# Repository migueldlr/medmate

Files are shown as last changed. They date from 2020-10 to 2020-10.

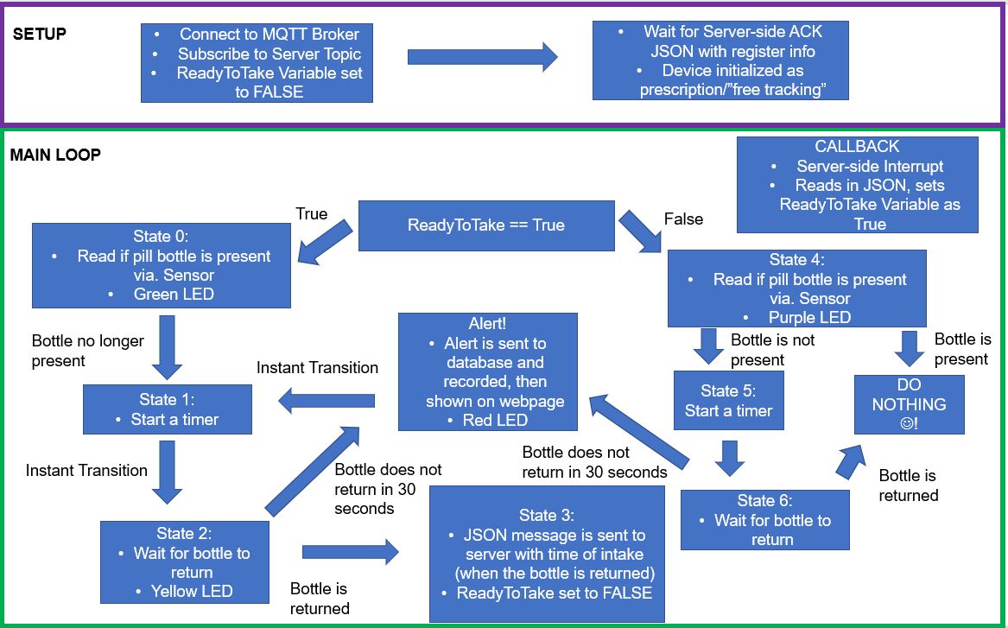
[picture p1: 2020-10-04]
images/MedMate State Machine.JPG

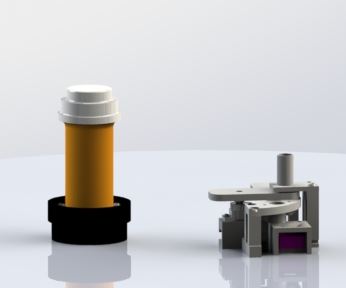
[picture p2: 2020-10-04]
images/MedMate Render.JPG

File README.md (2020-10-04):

# MedMate

`device/` contains the device's Arduino code

`server/` contains the Python that times events and facilitates communication between the device and the database

`client/` contains the React/TypeScript web project that allows users to input their prescriptions, track their medications, and receive updates

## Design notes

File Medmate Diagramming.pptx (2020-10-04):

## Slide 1

SETUP

- Connect to MQTT Broker
- Subscribe to Server Topic
- ReadyToTake Variable set to FALSE

- Wait for Server-side ACK JSON with register info
- Device initialized as prescription/”free tracking”

MAIN LOOP

CALLBACK
- Server-side Interrupt
- Reads in JSON, sets ReadyToTake Variable as True

State 4:
- Read if pill bottle is present via. Sensor
- Purple LED

True

ReadyToTake == True

False

State 0:
- Read if pill bottle is present via. Sensor
- Green LED

Bottle no longer present

Alert!
- Alert is sent to database and recorded, then shown on webpage
- Red LED

Instant Transition

Bottle is not present

State 5:
Start a timer

Bottle is present

State 1:
- Start a timer

Instant Transition

State 2:
- Wait for bottle to return
- Yellow LED

Bottle does not return in 30 seconds

State 3:
- JSON message is sent to server with time of intake (when the bottle is returned)
- ReadyToTake set to FALSE

DO NOTHING !

Bottle is returned

Bottle does not return in 30 seconds

State 6:
- Wait for bottle to return

Bottle is returned

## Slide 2

Prescription

User enters the following information
- Time of Prescription Intake (9am, 4pm)
- Frequency (Daily, Biweekly)
- Prescription Amount (# of pills)
- Prescription Name (Tylenol)
Server keeps track of when user should take medicine
- When it is time →
  - Sends JSON callback
  - Controller starts recording for medicine intake
  - Server stores time of intake into database

Free Tracking

User enters the following information:
- Prescription Name (Tylenol)
Server only tracks when user takes medicine
  - Controller can start recording for medicine intake at any point
  - Server stores time of intake into database

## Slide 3

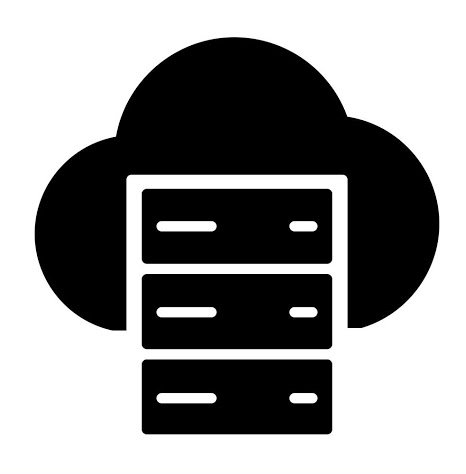
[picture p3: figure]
Best Free Icon Server Cartoon Vector Drawing » Free Vector Art, Images, Graphics & Clipart

Server keeps track of when user should take medicine

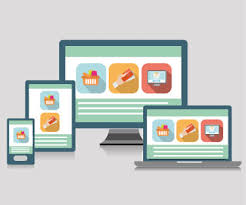
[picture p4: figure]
Web Page Cartoon - 2yamaha.com

User enters their prescription information

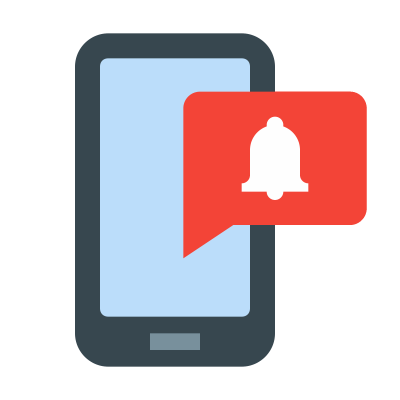
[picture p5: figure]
Notifications with Vera – Vera

User is notified to take medicine

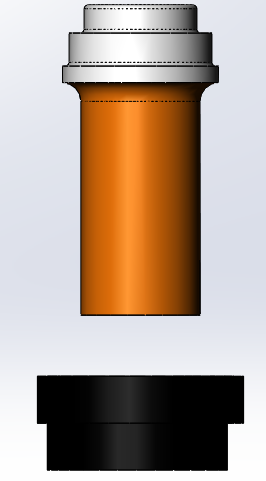
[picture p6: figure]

Pill bottle is taken off MedMate

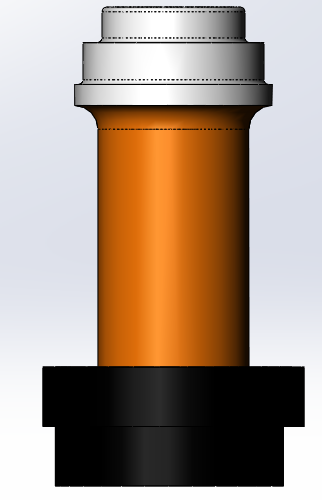
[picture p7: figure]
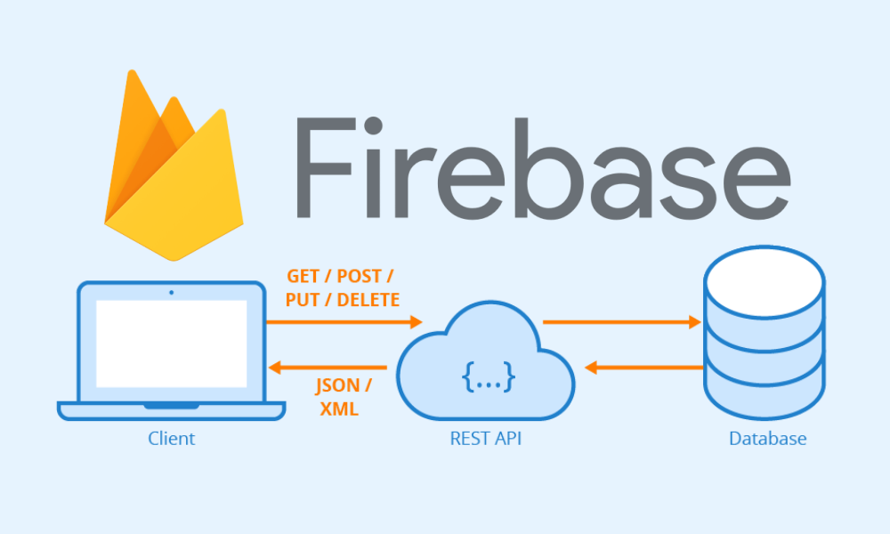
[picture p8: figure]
Firebase Cloud Functions Tutorial - Creating a REST API
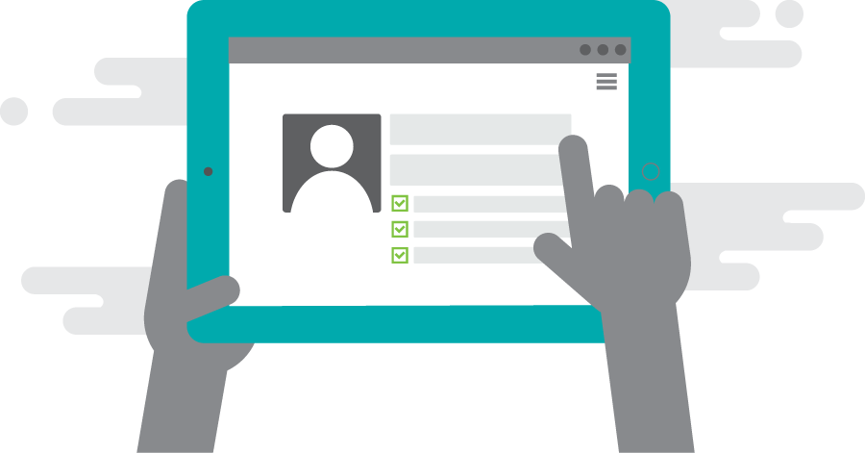
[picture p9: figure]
Streamlining Patient History Collection | Vynamic

Pills are consumed and bottle is put back on MedMate

Time of Intake is uploaded to Database

Patient History shown on Webpage

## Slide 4

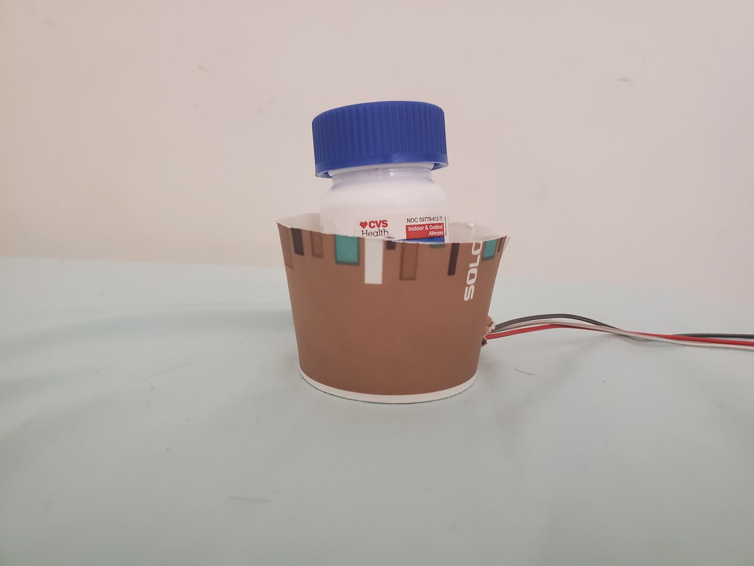
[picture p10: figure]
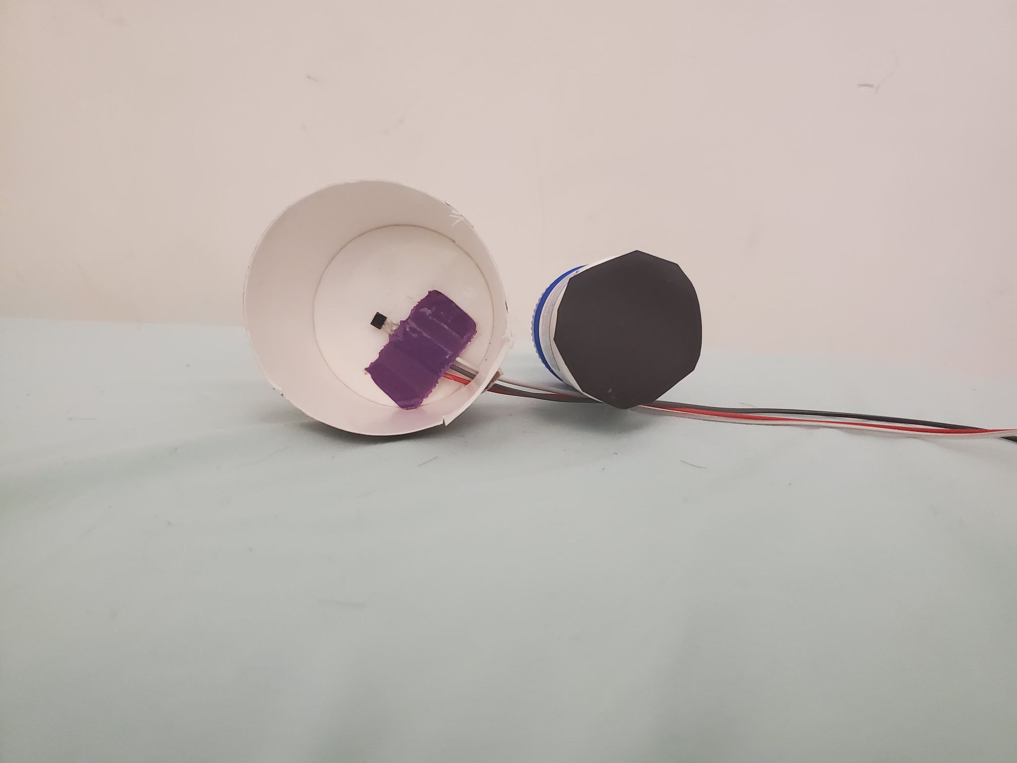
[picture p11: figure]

Pill Bottle

Paper Cup

DRV5053 Hall Sensor

Magnet

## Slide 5

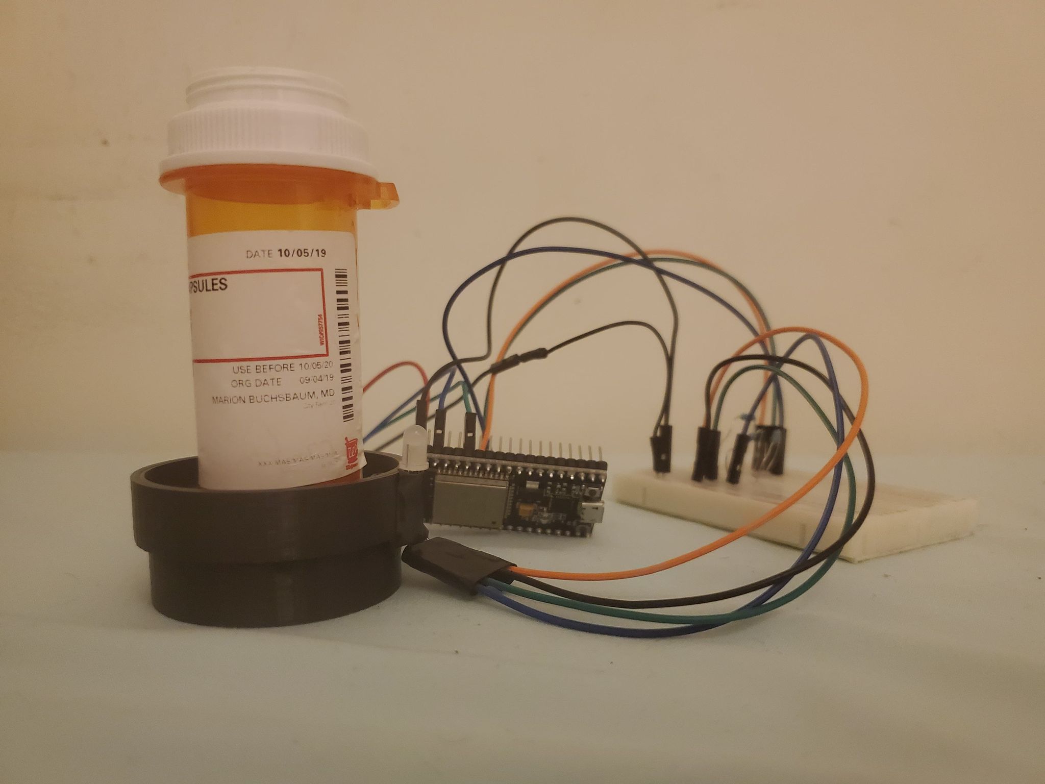
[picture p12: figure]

Pill Bottle

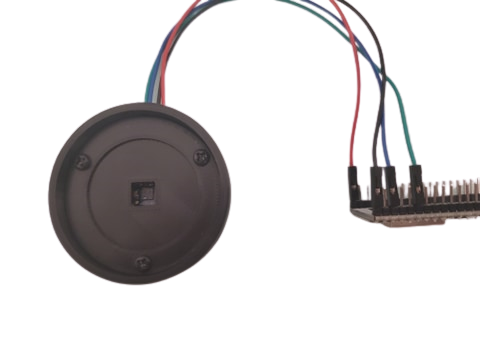
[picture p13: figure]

ESP32

VCNL4010 Proximity Sensor

MedMate

Multicolor LED

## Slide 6

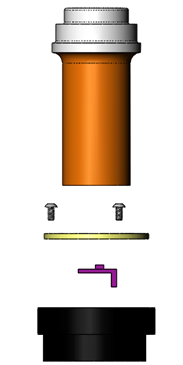
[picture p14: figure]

Pill Bottle

M3 Screws

VCNL4010 Proximity Sensor

Top Lid

Multicolor LED

Main Housing

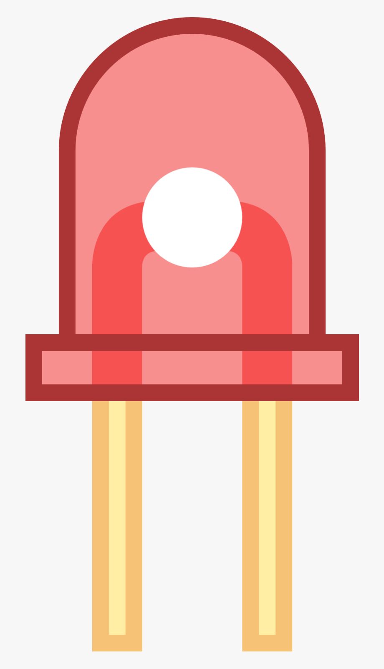
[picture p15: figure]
Image Result For Led Icon - Led Diode Icon Png , Transparent Cartoon, Free Cliparts & Silhouettes - NetClipart

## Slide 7

ESP32

VCNL4010

SCL (P22)

SDA (P21)

Red (P32)

Green (P33)

Blue (P25)

GND

SDA

SCL

3.3V

GND

Multicolor LED

Green

3.3V

220Ω

GND

Red

220Ω

220Ω

Blue

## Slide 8

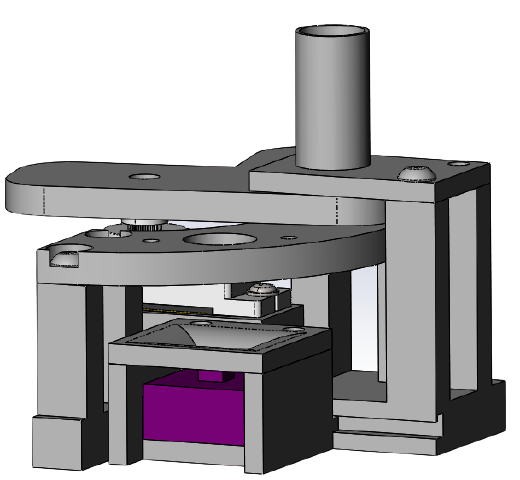
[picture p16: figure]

Rotating Cam

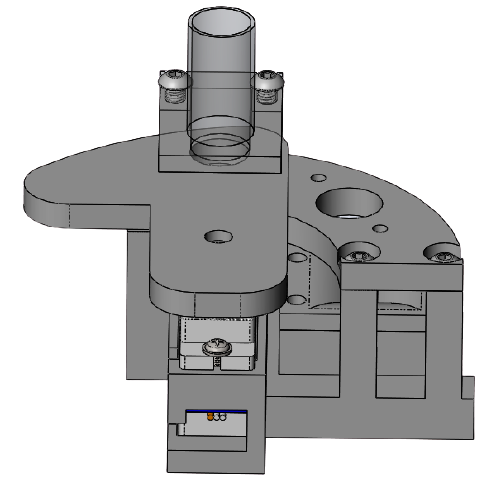
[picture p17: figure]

Pill Tube

Sorting Piece

Pill

VCNL4010 Proximity Sensor

Pill

Pill Holder

SG90 Servo

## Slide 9

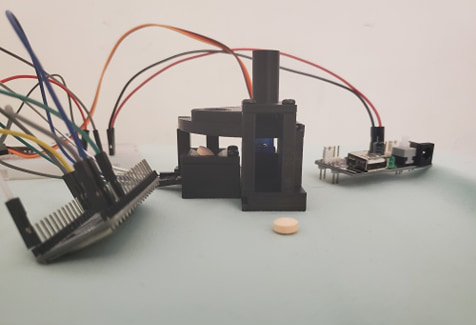
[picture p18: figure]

Pill Dispenser

SG90 Servo

5V Power Supply

Pill

ESP32

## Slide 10

ESP32

VCNL4010

SCL (P22)

SDA (P21)

P13 (PWM)

GND

SDA

SCL

3.3V

GND

3.3V

SG90 Servo

PWM

GND

GND

5V

5V Power Supply

5V

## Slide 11

Pill Dispenser State Machine

- Connect to MQTT Broker
- Subscribe to Server Topic
- ReadyToTake Variable set to FALSE

SETUP

- Wait for Server-side ACK JSON with register info
- Device initialized as prescription

CALLBACK
- Server-side Interrupt
- Reads in JSON, sets ReadyToTake Variable as True, sets # of pills to dispense

Wait for Callback

MAIN LOOP

True

ReadyToTake == True

State 0:
- # of Pills are dispensed

State 1:
- Check to see if pills are still in pill holder

False

Instant Transition

State 3:
- JSON message is sent to server with time of intake
- ReadyToTake set to FALSE

Pills are taken off holder

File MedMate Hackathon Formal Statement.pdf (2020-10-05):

Team/Device Name: MedMate

Team Members:
Stephen Mock
Miguel de los Reyes

Formal Statement

Description of Project:
MedMate is a device that helps patients and caretakers monitor medicine intake. MedMate comes in two forms: a pill bottle monitor and a pill dispenser. MedMate tracks when a user should take their prescription, senses when a user has taken their medicine, and then logs this information in a database that is presented on a webpage.

Webpage Link: https://medmate.vercel.app/
YouTube Demonstration: https://youtu.be/uWqPvaWqItg GitHub Link: https://github.com/migueldlr/medmate

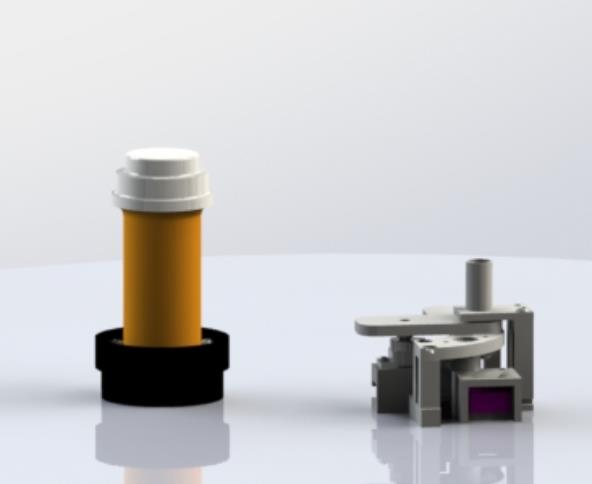
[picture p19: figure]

List of Hardware:

Hardware | Images

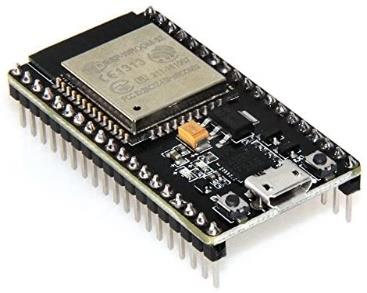
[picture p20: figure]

ESP32 IoT Microcontroller

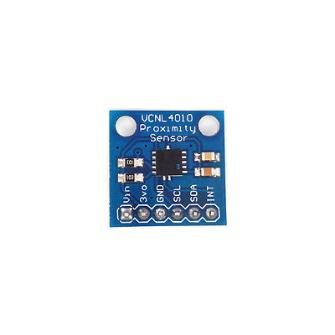
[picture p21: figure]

VCNL4010 Proximity Sensor

DRV5053 Analog-Bipolar Hall Effect Sensor

Tower Pro SG90

5V Power Supply

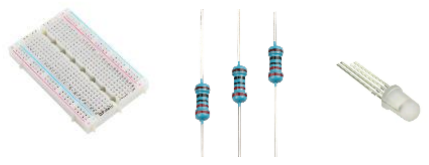
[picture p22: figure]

Breadboard, 220 Ohm Resistors, Multicolor LED

Tools Used:

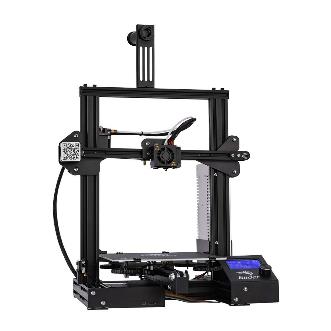
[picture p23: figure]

Ender 3 Printer

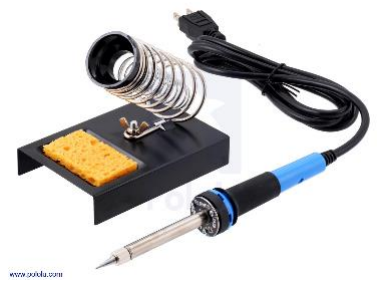
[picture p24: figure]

Solder

Software Used:
- Arduino C (C/C++)
- Eclipse Paho MQTT Python client (Python)
- Cloud Firestore (Google Firebase)
- React (JS)

Protocols:
- MQTT (Message Queuing Telemetry Transport)
- I2C (Inter-Integrated Circuit)

Process of Creating Project:
The motivation to create MedMate was to help Stephen’s Dad track his medications. We wanted to create a system that would not only remind his father to take his medicine, but also monitor intake history.
The design philosophy was the following
- Low profile
- Cheap
- Simple hardware
- Simple user interface
- Interfaces with any standard pill bottle
ESP32 was our chosen controller because it is configurable with the Arduino client and has full IoT functionality. The chosen network protocol was MQTT, as it is designed for simple communication between a controller and host server.
MedMate has two modes: Prescription and “free tracking”, as shown in the following figure:

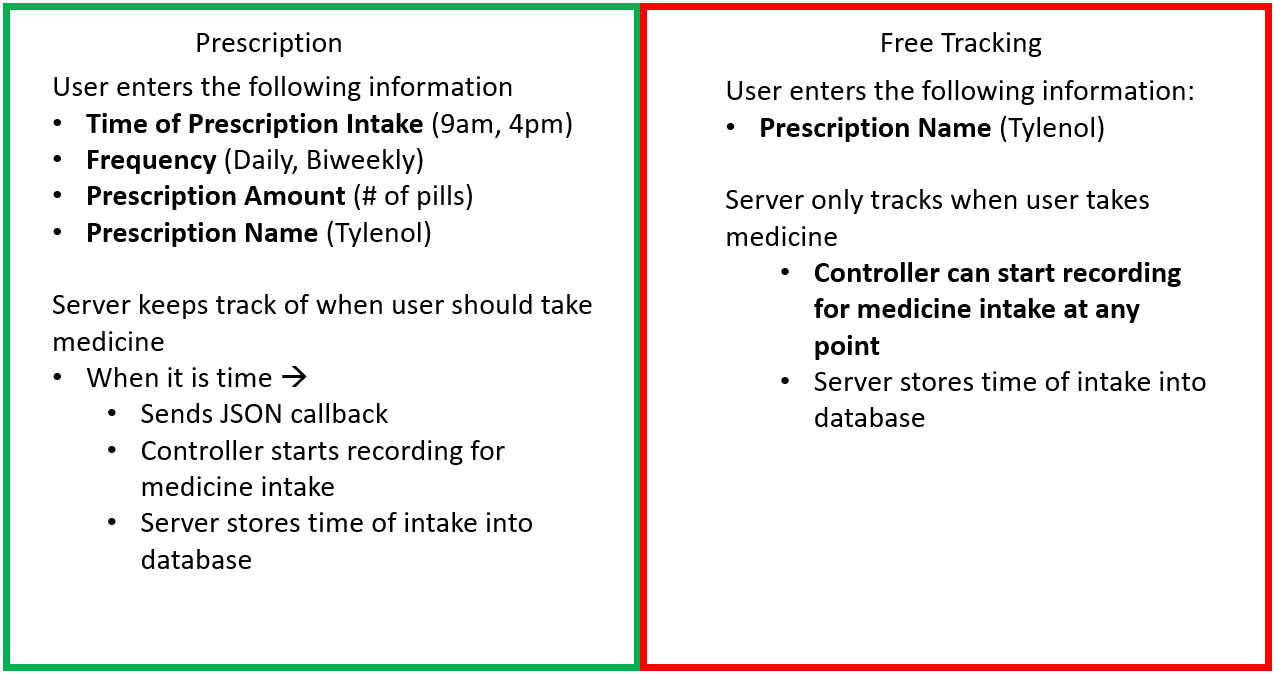
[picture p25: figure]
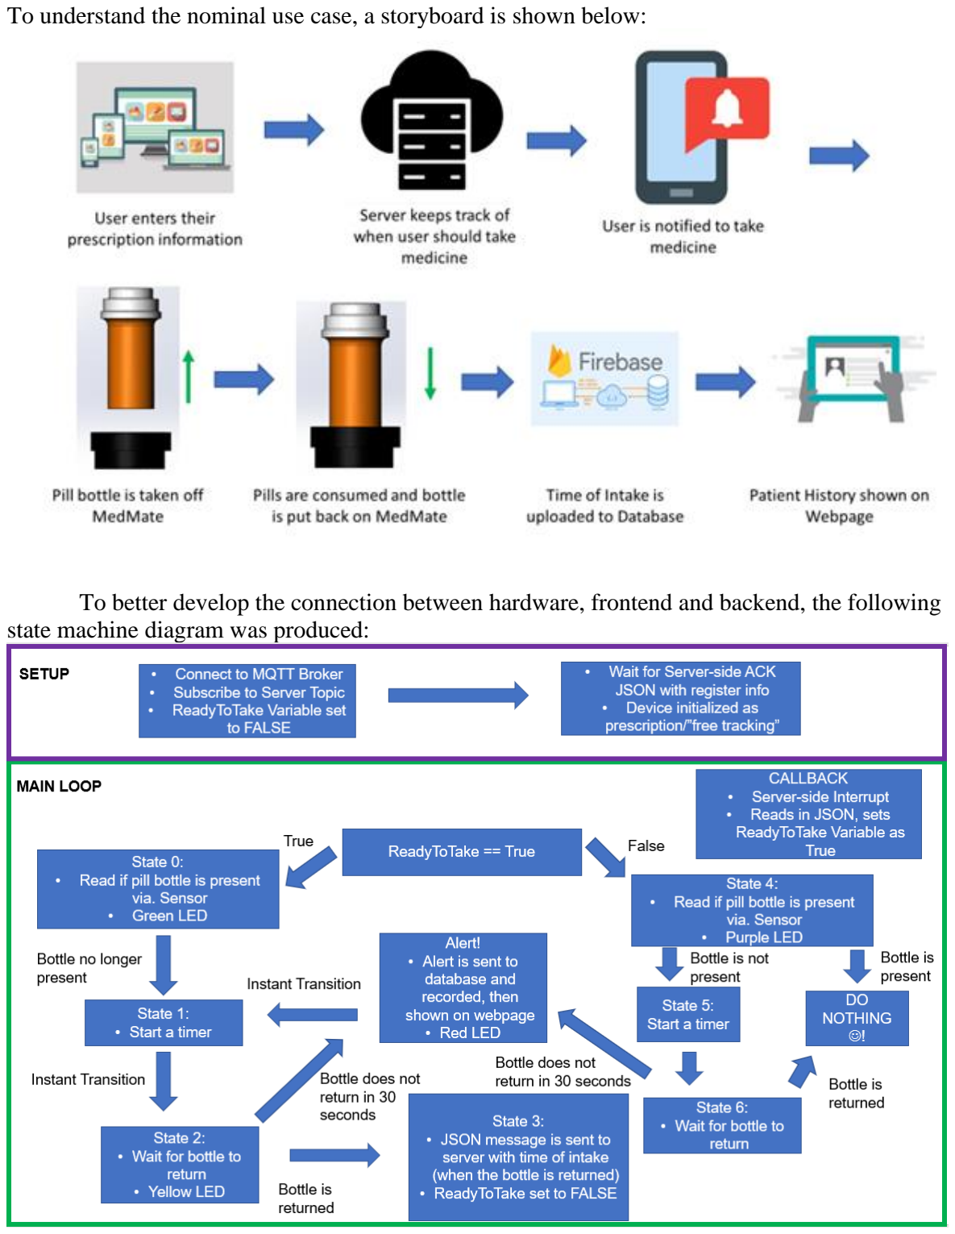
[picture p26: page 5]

To understand the nominal use case, a storyboard is shown below:

To better develop the connection between hardware, frontend and backend, the following state machine diagram was produced:

To summarize, the server (our computer) uses threads to determine when a user should take medicine. When it is time, a JSON message is sent to the device and read via callback, signaling the device to start recording for when a user takes medicine. This changes the “ReadyToTake” variable. The device waits for the user to pick up and put back down the device, then records when this operation occurs. This is recorded in a Firebase database for the webpage to process. If a user does not return the pill bottle after a set time, an alert will be sent to the database and shown on the webpage. To communicate, JSON formatted messages were sent between the server and device as shown:


Additionally, the server-side operations and control flow are shown in this figure:

The first prototype used a hall effect sensor to monitor if the pill bottle is present. The sensor was glued to a paper cup, and a magnet was attached to the bottle. When the bottle was in the cup, the hall sensor sensed that it was there via. the magnet.


A second prototype was developed, and 3D printed, but instead used a VCNL4010 proximity sensor. This sensor was more robust and used I2C. Saturation and averaging was implemented for more reliability. A magnet was not required on the pill bottle and the system was easy to assemble, fitting our design philosophy.


Lastly, a third prototype was developed. This was a pill dispenser, which automatically dispenses at a set time. It implements a servo, but still uses the VCNL4010 for sensing if medicine is present after dispensing. It follows the similar server to device logic for communicating when to dispense. This device demonstrated a higher level of fidelity by having control over how much medicine the user can take.


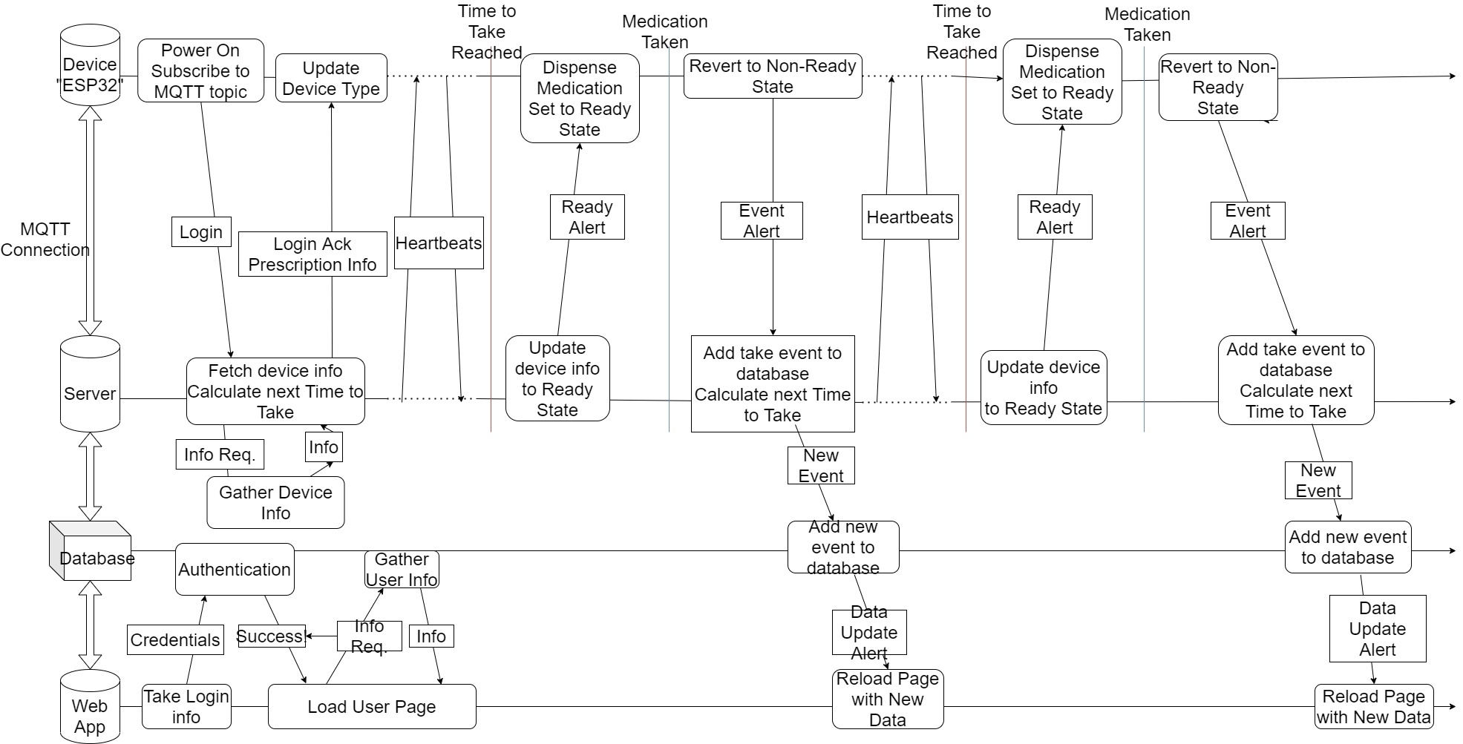
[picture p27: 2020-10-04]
images/Fullstack Flow.png

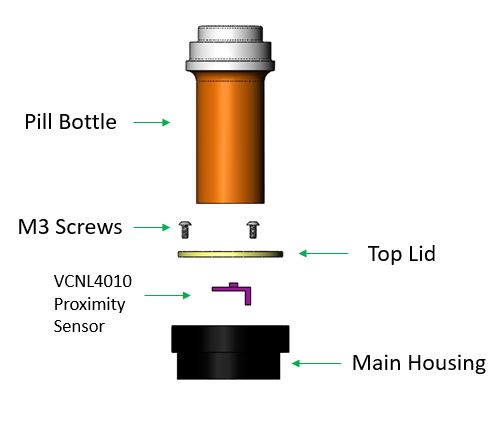
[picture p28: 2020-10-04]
images/Bottle Holder.JPG

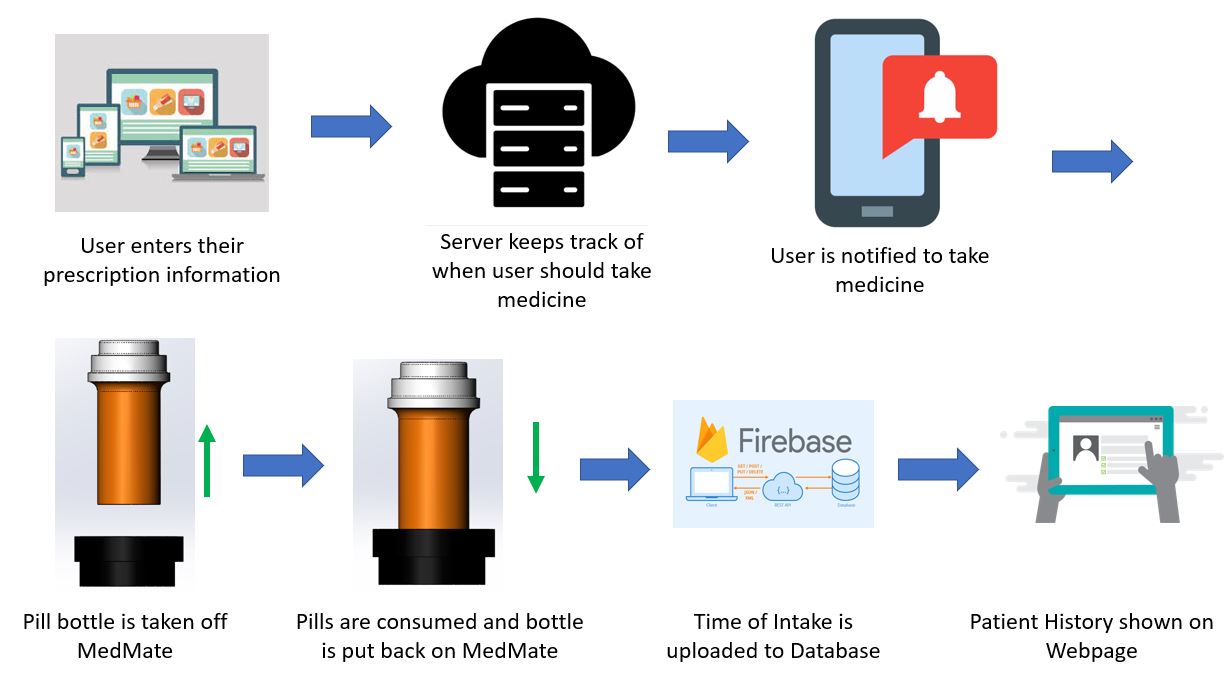
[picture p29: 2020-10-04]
images/MedMate Storyboard.JPG

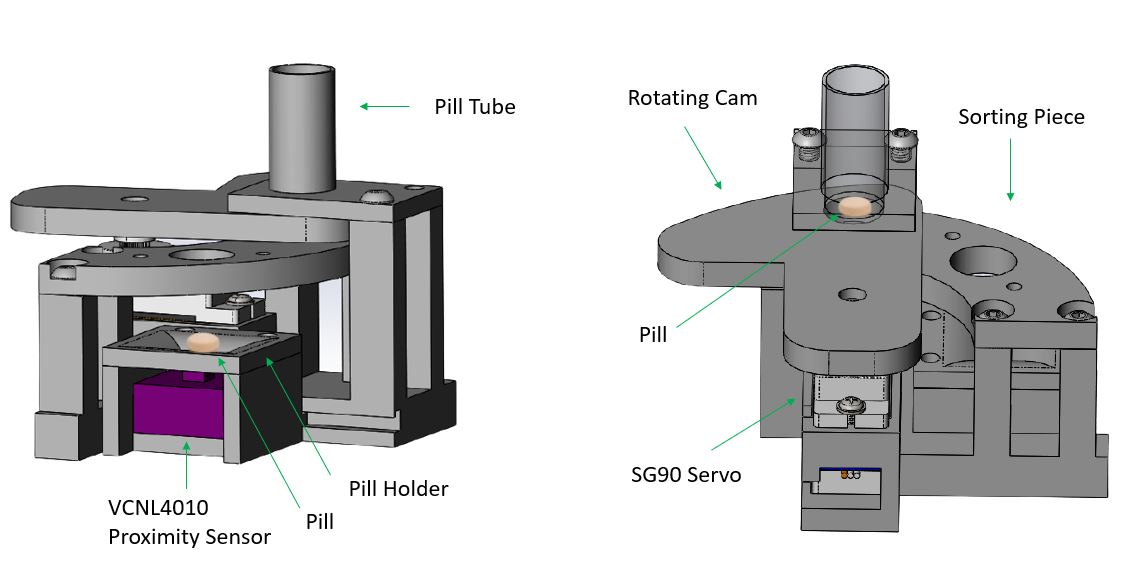
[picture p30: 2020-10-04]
images/Pill Dispenser.JPG

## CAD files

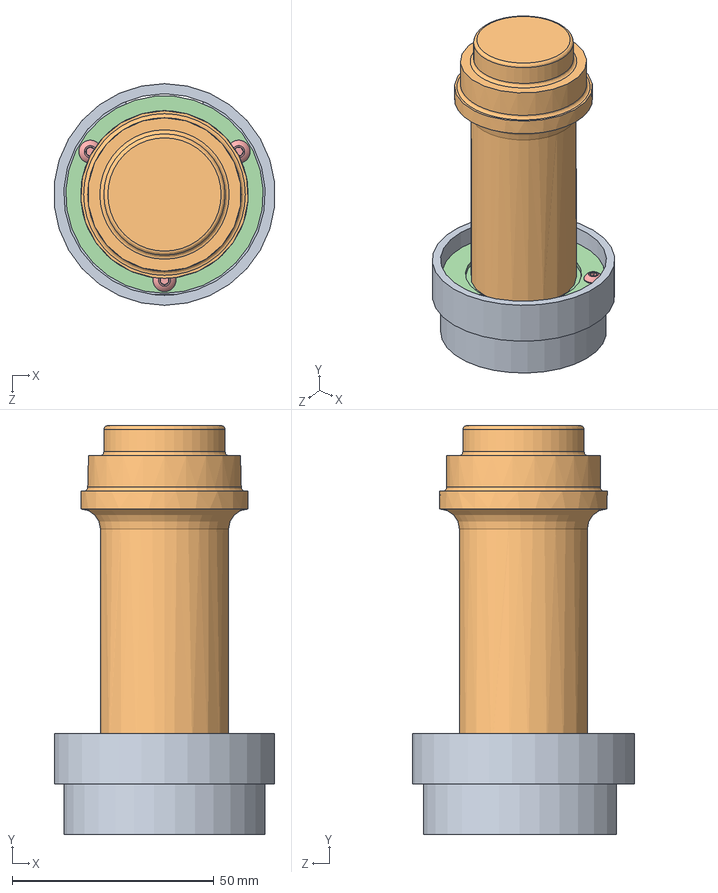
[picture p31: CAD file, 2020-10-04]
cad/full assembly v1.SLDASM
54.7 x 101.5 x 55.0 mm
main housing v1
bottle v1
PCB proximity sensor
top lid
92095A179_M3 SCREW x 3

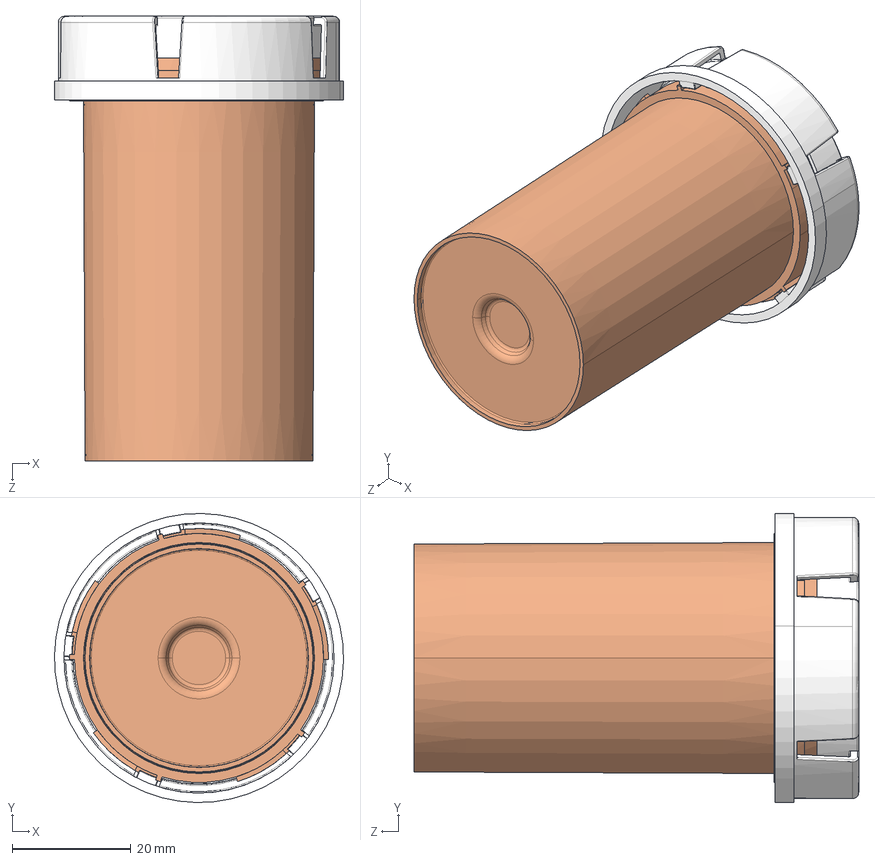
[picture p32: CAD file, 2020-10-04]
cad/Ensamblaje.STEP
48.6 x 48.6 x 74.8 mm
Frasco
Tapa
Pastilla x 5

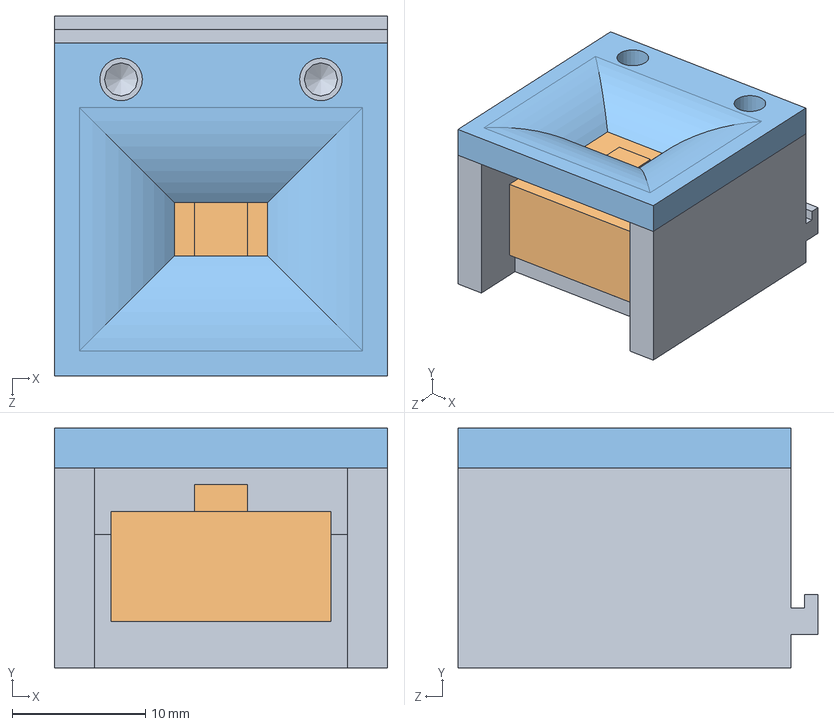
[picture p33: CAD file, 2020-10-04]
cad/v2/pill holder/pill holder assembly.SLDASM
25.0 x 18.0 x 27.0 mm
pill holder
PCB proximity sensor
pill holder lid

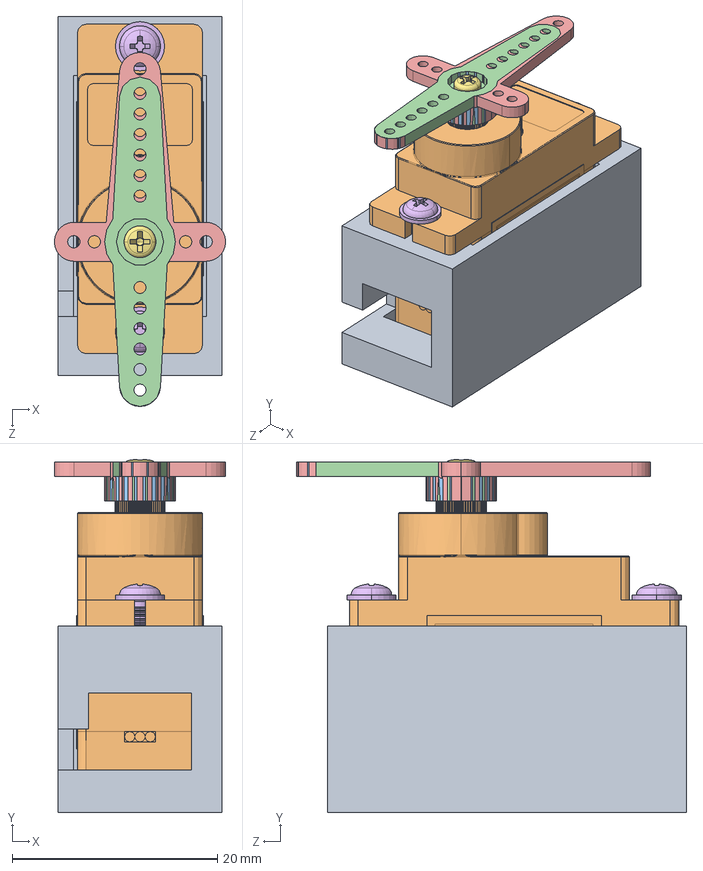
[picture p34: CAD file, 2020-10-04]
cad/v2/printing tests/servo mount test with servo.SLDASM
16.7 x 34.4 x 38.0 mm
servo mount test
SG90 - Micro Servo 9g - Tower Pro.1_Pe_a.STEP
SG90 - Micro Servo 9g - Tower Pro.4_Pe_a.STEP
SG90 - Micro Servo 9g - Tower Pro.5_BS EN ISO 7045 - M2 x 8 - Z - 8S.STEP x 2
SG90 - Micro Servo 9g - Tower Pro.6_BS EN ISO 7045 - M2 x 4 - Z - 4S.STEP

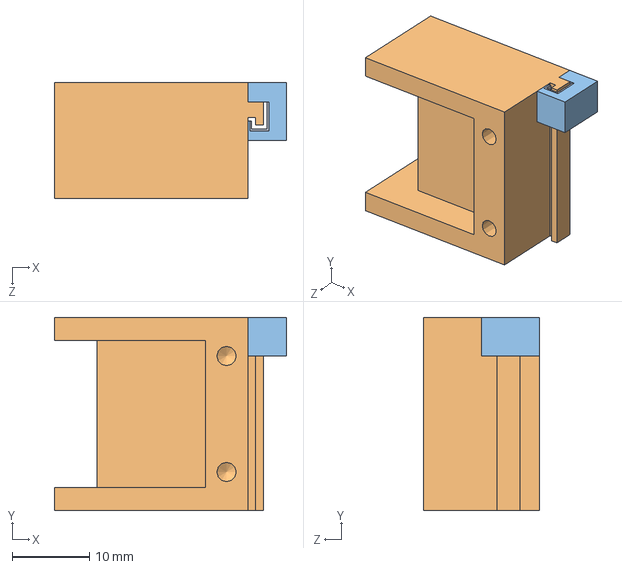
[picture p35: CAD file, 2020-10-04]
cad/v2/printing tests/slider test with pill container.SLDASM
30.0 x 25.0 x 15.0 mm
pill holder
slider test 2

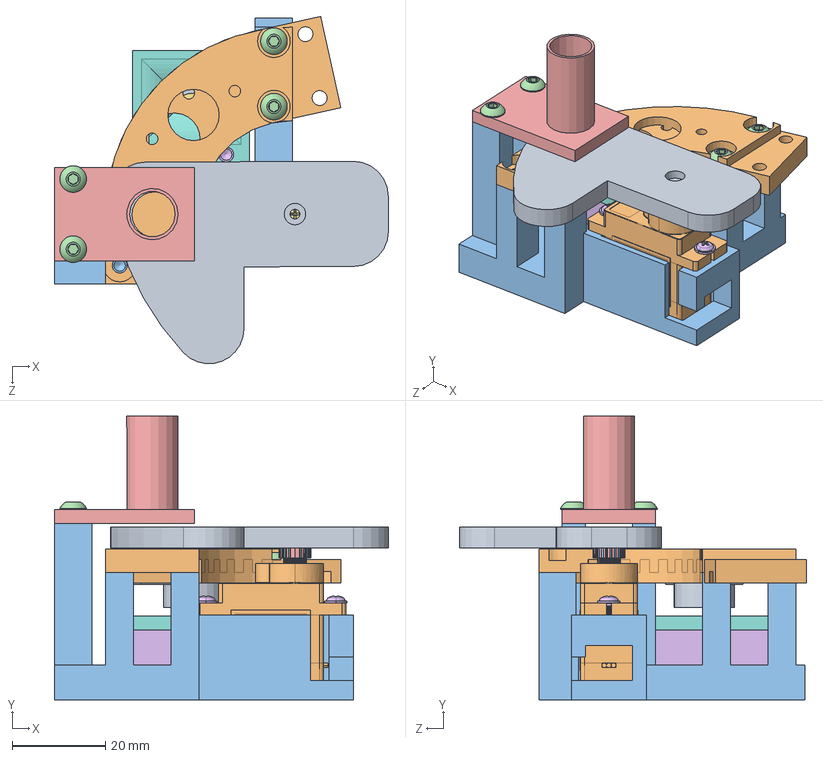
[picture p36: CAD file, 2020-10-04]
cad/v2/servo system.SLDASM
71.5 x 60.8 x 74.3 mm
rotating part
frame
semicircle for rotating part
92095A179_M3 SCREW x 4
top tube
pill holder
PCB proximity sensor
pill holder lid
SG90 - Micro Servo 9g - Tower Pro.1_Pe_a.STEP
SG90 - Micro Servo 9g - Tower Pro.4_Pe_a.STEP
SG90 - Micro Servo 9g - Tower Pro.5_BS EN ISO 7045 - M2 x 8 - Z - 8S.STEP x 2
SG90 - Micro Servo 9g - Tower Pro.6_BS EN ISO 7045 - M2 x 4 - Z - 4S.STEP

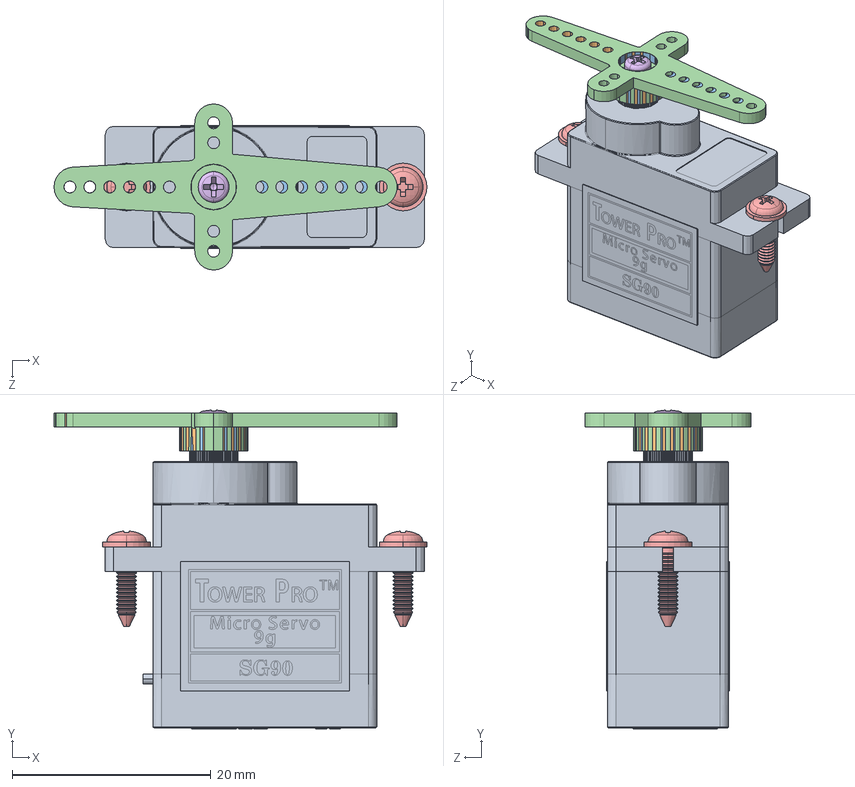
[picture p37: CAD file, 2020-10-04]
cad/v2/SG90 - Micro Servo 9g - Tower Pro.SLDASM
37.5 x 32.0 x 16.7 mm
SG90 - Micro Servo 9g - Tower Pro.1_Pe_a.STEP
SG90 - Micro Servo 9g - Tower Pro.4_Pe_a.STEP
SG90 - Micro Servo 9g - Tower Pro.5_BS EN ISO 7045 - M2 x 8 - Z - 8S.STEP x 2
SG90 - Micro Servo 9g - Tower Pro.6_BS EN ISO 7045 - M2 x 4 - Z - 4S.STEP

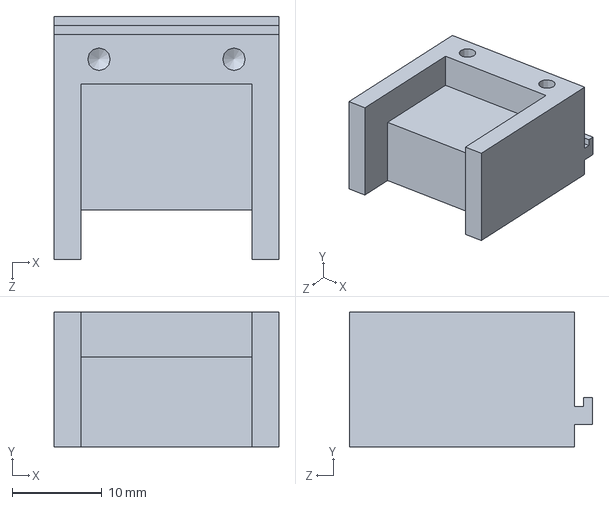
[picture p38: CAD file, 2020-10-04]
cad/v2/pill holder/pill holder.SLDPRT
25.0 x 15.0 x 27.0 mm

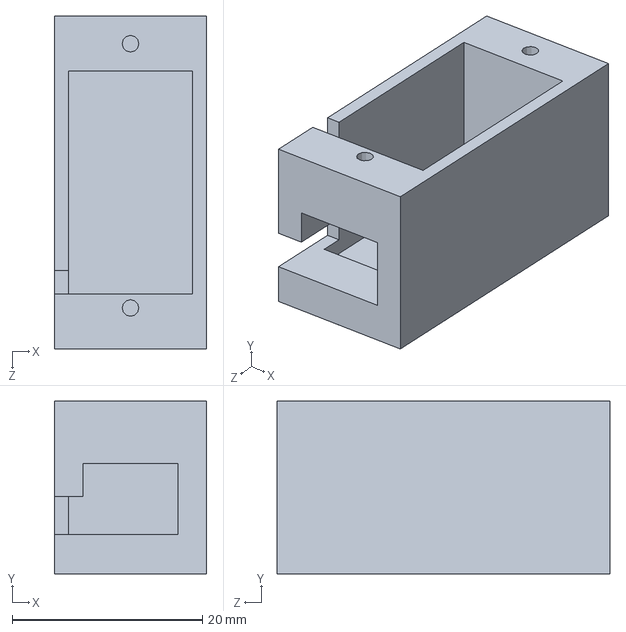
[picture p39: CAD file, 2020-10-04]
cad/v2/printing tests/servo mount test.SLDPRT
16.0 x 18.2 x 35.0 mm

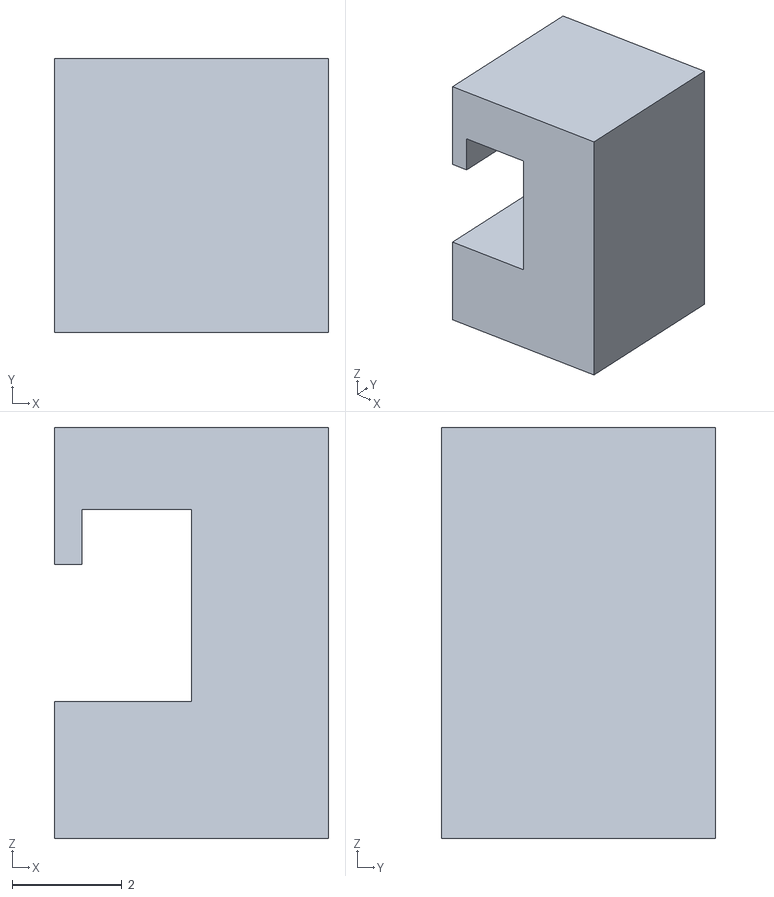
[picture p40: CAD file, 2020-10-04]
cad/v2/STL files/slider test.STL
5.00 x 5.00 x 7.50

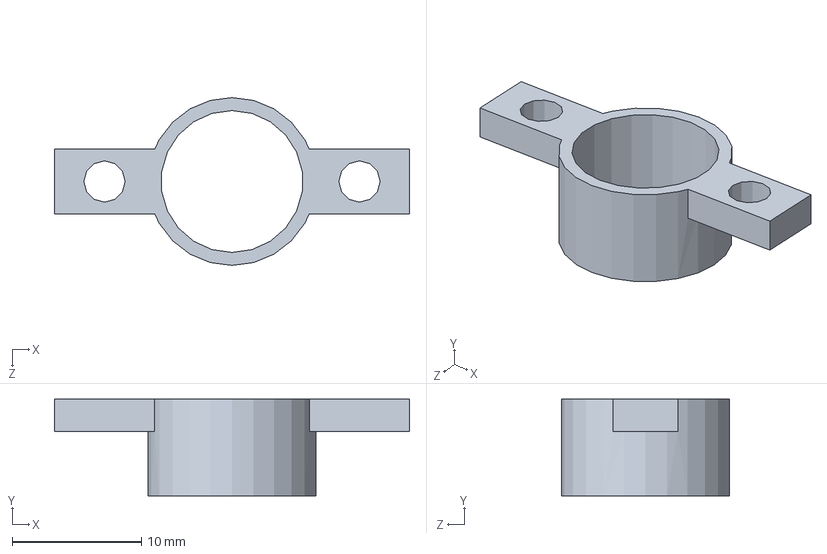
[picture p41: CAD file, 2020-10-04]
cad/v2/tube2.SLDPRT
27.5 x 7.50 x 13.0 mm

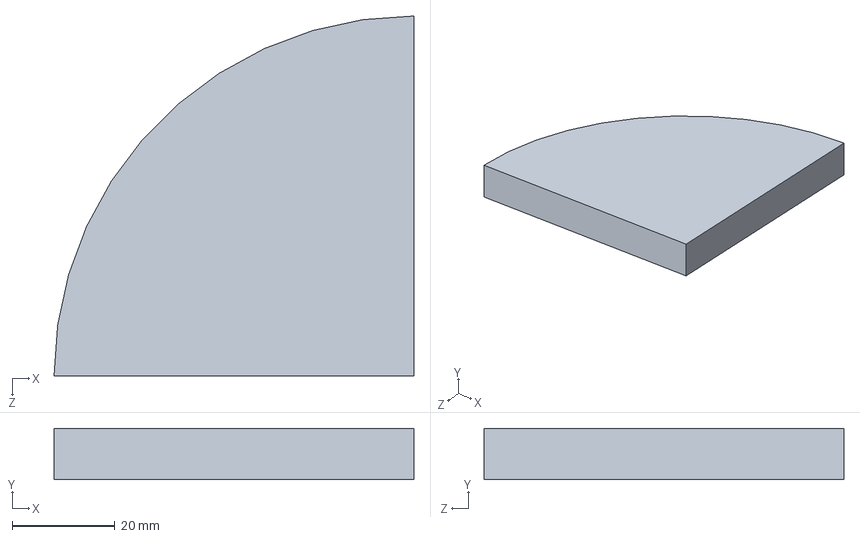
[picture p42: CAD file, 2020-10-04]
cad/v2/rotating part 2.SLDPRT
70.0 x 10.0 x 70.0 mm

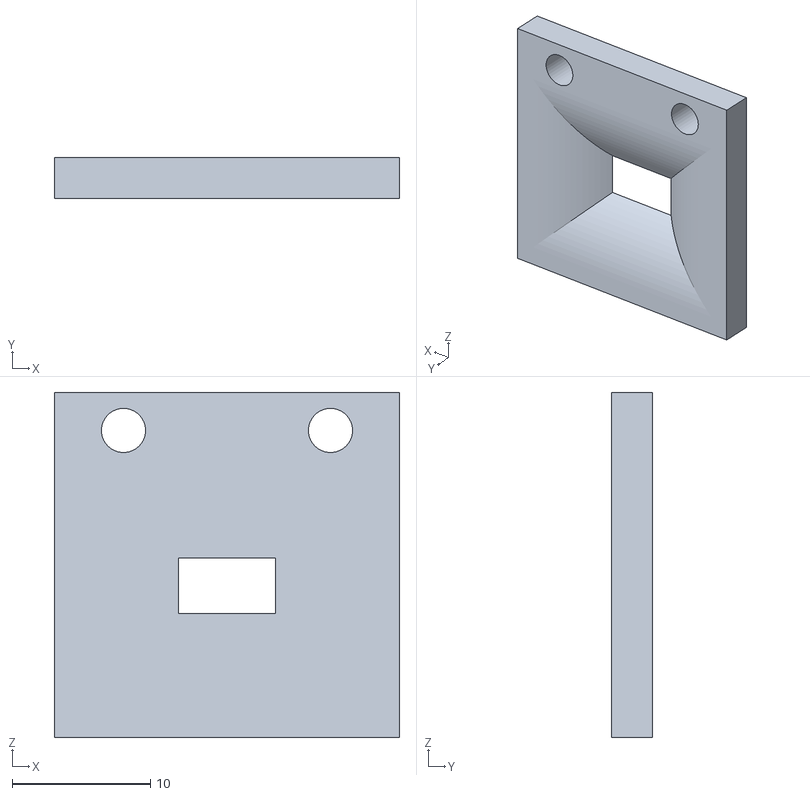
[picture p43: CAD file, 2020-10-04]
cad/v2/STL files/pill holder lid.STL
25.0 x 3.00 x 25.0

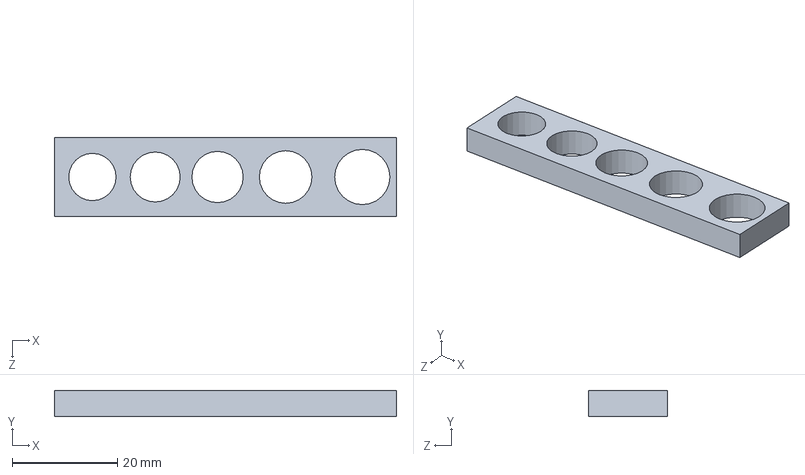
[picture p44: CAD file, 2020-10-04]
cad/v2/printing tests/hole size tests.SLDPRT
65.0 x 5.00 x 15.0 mm

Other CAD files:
cad/v2/pill dispenser.SLDASM
cad/v2/pill holder/pill holder lid.SLDPRT
cad/v2/servo base.SLDPRT
cad/v2/STL files/slider test 2.STL
cad/v1/91772A106_18-8 SS PAN HEAD PHILLIPS MACHINE SCREW.SLDPRT
cad/v1/92095A179_M3 SCREW.SLDPRT
cad/v1/PCB proximity sensor.SLDPRT
cad/v1/STL files/additional leg.STL
cad/v1/STL files/bottle holder v1.STL
cad/v1/STL files/rotating part.STL
cad/v1/STL files/top lid.STL
cad/v1/bottle holder v1.SLDPRT
cad/v1/bottle v1.SLDPRT
cad/v1/full assembly bottle holder v1.SLDASM
cad/v1/main housing v1.SLDPRT
cad/v1/pill attempt 1.SLDPRT
cad/v1/printing tests/#4 tap and clearance test.SLDPRT
cad/v1/printing tests/#4 tap and clearance test.STL
cad/v1/printing tests/M3 tap and clearance test.SLDPRT
cad/v1/printing tests/M3 tap and clearance test.STL
cad/v1/printing tests/additional leg.SLDPRT
cad/v1/top lid.SLDPRT
cad/v2/4WaySurfaceMount.SLDPRT
cad/v2/STL files/frame.STL
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

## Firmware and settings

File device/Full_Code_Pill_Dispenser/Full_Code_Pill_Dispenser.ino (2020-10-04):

//Stephen Mock
// 10-2-20
// Full Code for Pill Dispenser (Not Holder)

#include <WiFi.h>
#include "time.h"
#include <PubSubClient.h>
#include <ArduinoJson.h>
#include <Wire.h>
#include "Adafruit_VCNL4010.h"
#include <Servo.h>

Adafruit_VCNL4010 vcnl;

// WIFI 
#define SECRET_SSID "FiOS-3VPP9"    // replace MySSID with your WiFi network name
#define SECRET_PASS "eat2359omni564bare"  // replace MyPassword with your WiFi password
char ssid[] = SECRET_SSID;   // your network SSID (name) 
char pass[] = SECRET_PASS;   // your network password
int keyIndex = 0;            // your network key Index number (needed only for WEP)


// Time Capture
char nowHourChar[30]; //vector used to convert characters --> integers
char nowMinChar[30]; 
char nowDateChar[30]; 

// MQTT
const char* mqtt_server = "mqtt.eclipse.org";
WiFiClient espClient;
PubSubClient client(espClient);
unsigned long lastMsg = 0;
#define MSG_BUFFER_SIZE  (50)
char msg[MSG_BUFFER_SIZE];
int value = 0;
int nowHour; // integer representing the current hour
int nowMin; // integer representing the current minute
int nowDate; 

// Timing
unsigned long putBackTimer = 0; // timer representing how much time you have to put back the medicine before an alert will trigger
 
//Time Library
const char* ntpServer = "pool.ntp.org";
const long  gmtOffset_sec = -18000; // Five hours behind in EST? have to check.
const int   daylightOffset_sec = 3600;

//Magnet Setup
int state = 0; // starts default at 0
int state2 = 0;  // starts default at 0 
boolean medPresent;

// Servo
int currPos = 45;
Servo myservo;
int amount = 0;

// USER INFO
boolean readyToTake = false; //ready take token, default as TRUE... unless specified on startup
boolean prescription = false; // by default... this should be false
String userID = "null"; // user ID
String prescriptionID;




/* Setup Functions
 *  
 */




/*
 * Wakeup Function
 */

void startUpMsg() {
   StaticJsonDocument<200> jsonBuffer;
   JsonObject root = jsonBuffer.to<JsonObject>();
   root["deviceId"] = "device1"; // take what is read in, and publish it back to the user
   root["type"] = "register";
   serializeJson(root, Serial);
   char buffer[256];
   serializeJson(root, buffer);
   client.publish("medmate/dev/ESP32Test/d2s", buffer);
   Serial.println("STARTUP MESSAGE");
   delay(5000);
}


void setup_wifi() {

  delay(10);
  // We start by connecting to a WiFi network
  Serial.println();
  Serial.print("Connecting to ");
  Serial.println(ssid);

  WiFi.mode(WIFI_STA);
  WiFi.begin(ssid, pass);

  while (WiFi.status() != WL_CONNECTED) {
    delay(500);
    Serial.print(".");
  }

  randomSeed(micros());

  Serial.println("");
  Serial.println("WiFi connected");
  Serial.println("IP address: ");
  Serial.println(WiFi.localIP());
}


void callback(char* topic, byte* payload, unsigned int length) {
  StaticJsonDocument<256> doc;
  deserializeJson(doc, payload, length);
  serializeJsonPretty(doc, Serial);

  /* There are 5 fields that you can accept:
   *  type: the type of message being sent
   *  userID: the userID to have stored onto this device
   *  prescription: a boolean representing if the device should go into "prescription mode" or not
   *  prescriptionID: an ID associated with a specific prescription
   *  readyToTake: a boolean telling the device if it is time for a user to take the medicine
  */
  
  if (userID.equals("null")) { // If there is no value to the userID... then assign it at the startup, and then this should be the same for the user for all calls.
      const char* newID = doc["userID"];
      userID = newID;
  }
  
  prescription = doc["prescription"];
  const char* newPrescriptionID = doc["prescriptionID"];
  prescriptionID = newPrescriptionID;
  readyToTake = doc["readyToTake"];
  amount = doc["amount"];
  Serial.print("READYTOTAKE?");
  Serial.println(readyToTake);
  Serial.println(" CALL BACK !!!");
}


void reconnectWifi() {
    Serial.print("Attempting to reconnect to SSID: ");
    Serial.println(SECRET_SSID);
    while(WiFi.status() != WL_CONNECTED){
      WiFi.begin(ssid, pass); // Connect to WPA/WPA2 network. Change this line if using open or WEP network
      Serial.print(".");
      delay(1000);     
    } 
    Serial.println("\nReconnected.");
}

void reconnect() {
  // Loop until we're reconnected
  while (!client.connected()) {
    Serial.print("Attempting MQTT connection...");
    // Create a random client ID
    String clientId = "Stephen Mock";
    clientId += String(random(0xffff), HEX);
    // Attempt to connect
    if (client.connect(clientId.c_str())) {
      Serial.println("connected");
      client.subscribe("medmate/dev/ESP32Test/s2d"); // subscribe to the server --> device network
    } else {
      Serial.print("failed, rc=");
      Serial.print(client.state());
      Serial.println(" try again in 5 seconds");
      // Wait 5 seconds before retrying
      delay(5000);
    }
  }
  delay(1000);
}


void setup() {  
  Serial.begin(115200);  //Initialize serial
  setup_wifi();
  client.setServer(mqtt_server, 1883);
  client.setCallback(callback);
  configTime(gmtOffset_sec, daylightOffset_sec, ntpServer); // setting up time
  putBackTimer = millis(); //initialize it as the time the program starts
  if (! vcnl.begin()){ //Initializing sensor
    Serial.println("Sensor not found :(");
    while (1);
  }
  Serial.println("Found VCNL4010");
  reconnect();
  startUpMsg();
  myservo.attach(13);  // attaches the servo on pin 13 to the servo object
  servoMove(90);
}

void loop() {
  
  // Connect or reconnect to WiFi
  if(WiFi.status() != WL_CONNECTED){
    reconnectWifi();
  }
  if (!client.connected()) {
    reconnect();
  }

  
  if (readyToTake) { // It is time to take the medicine
    switch (state) {
      case 0:
        dispense(amount);
        state = 1;
      break;

      case 1:
        while(state == 1) { 
          // wait for 10 seconds before an alert, otherwise keep waiting for the medicine to return
          sensorReadAndAverage(10);

          if (!medPresent) { 
            state = 2; // medicine has been taken, time to transition !
            Serial.println("Transition to State 2");
          }
      break;

      case 2:
          eventSend(); // success.. send a positive event to the server
          state = 0; // resetting
          readyToTake = false;
          Serial.println("ALL DONE");
          delay(2000);
      break;
    }
    Serial.print("State1 : ");
    Serial.println(state);
    
    }
  } else { // It is not time to take the medicine
      client.loop(); // Just wait until it is time to dispense again... nothing else to do
      Serial.println("WAITING...");
  }
}



/*
 * Helper Functions
 */

// Dispenses a set amount of pills
void dispense(int numPills) {
  for (int i = 0; i < numPills; i++) {
    servoMove(90);
    delay(1000);
    servoMove(45);
    delay(2000);
  }
  Serial.print(numPills);
  Serial.println(" dispensed");
}

// Servo Function that helps to smooth the process, and make sure that it doesnt move too quickly
void servoMove(int angle) {

 if (angle > currPos) {
    for ( ; currPos <=  angle; currPos += 1) { // goes from 0 degrees to 180 degrees
      // in steps of 1 degree
          Serial.println(currPos);
          myservo.write(currPos); // Servo 0 (X ROT)
      delay(30);                       // waits 15ms for the servo to reach the position
    }
 } else {
    for ( ; currPos >=  angle; currPos -= 1) { // goes from 0 degrees to 180 degrees
           myservo.write(currPos); // Servo 0 (X ROT)
           delay(30);                       // waits 15ms for the servo to reach the position
   }
 }
}





// Gets the current time and stores it into two int variables, nowHour and nowMin which are numerical representatives of the hour / time (military time)
 
void getCurrentTime() {
  struct tm timeinfo;
  if(!getLocalTime(&timeinfo)) {
    Serial.println("Failed to obtain time");
    return;
  }
  // Storing the Hours, Minutes, and Date into various character arrays
  strftime(nowHourChar, 30, "%H", &timeinfo);
  strftime(nowMinChar, 30, "%M", &timeinfo);
  strftime(nowDateChar, 30, "%d", &timeinfo);
  nowHour = atoi(nowHourChar);
  nowMin = atoi(nowMinChar);
  nowDate = atoi(nowDateChar);
  
}


/* Main Functions
 *  The main functions are medicineAddTime(), readFutureTime(), magnetReadAndAverage(), alertUser(), updateDatabase()
 *  
 *  
 */


/*
 *  This function is when a normal event occurs. This means the behavior used the device as intended, and there is no reason to alert or have a change in behavior.
 */
 
void eventSend() {
  StaticJsonDocument<200> jsonBuffer;
  JsonObject root = jsonBuffer.to<JsonObject>();
  root["userID"] = userID; // take what is read in, and publish it back to the user
  root["type"] = "s_event";
  root["prescription"] = prescription;
  root["prescriptionID"] = prescriptionID;
  getCurrentTime();
  root["date"] = nowDate;
  root["hour"] = nowHour;
  root["min"] = nowMin;
  serializeJson(root, Serial);
  char buffer[256];
  serializeJson(root, buffer);
  client.publish("medmate/dev/ESP32Test/d2s", buffer);
  delay(2000);
}


/*
 *  This function is when an alert occurs. The errors are all the same, so the type is only "alert" for now. 
 */

void alertServer() {
  StaticJsonDocument<200> jsonBuffer;
  JsonObject root = jsonBuffer.to<JsonObject>();
  root["userID"] = userID; // tell the device which user the alert is tied to (stored on startup)
  root["type"] = "alert";
  getCurrentTime();
  root["date"] = nowDate;
  root["hour"] = nowHour;
  root["min"] = nowMin;
  serializeJson(root, Serial);
  char buffer[256];
  serializeJson(root, buffer);
  client.publish("medmate/dev/ESP32Test/d2s", buffer);
  delay(2000);
}


/*
 * Returns a boolean of whether the device is there or not based on the magnet read values that are averaged with 100 samples.
 * Input is the amount of samples that it takes every time the function runs
 */
void sensorReadAndAverage(int numSamples) { 
  int proximitySum = 0; // sum of all the samples
   for (int i = 0; i < numSamples; i++) { // sampling 100 times before deciding on the magnetVal value
          int proximityRead = vcnl.readProximity();
          proximitySum = proximitySum + proximityRead;
        }
   proximitySum = proximitySum / numSamples; // averaging
   
   if (proximitySum < 10000) { // based on the threshhold of the sensor, general testing
    medPresent = false;
   } else {
    medPresent = true; 
   }
   Serial.print("medPresent?: ");
   Serial.println(medPresent);
}

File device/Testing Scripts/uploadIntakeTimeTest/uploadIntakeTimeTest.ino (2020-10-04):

/*
Using the online time server, upload the exact time (as string) when things are being done
*/

#include "ThingSpeak.h"
#include <WiFi.h>
#include "time.h"

// WIFI 
#define SECRET_SSID "FiOS-3VPP9"    // replace MySSID with your WiFi network name
#define SECRET_PASS "eat2359omni564bare"  // replace MyPassword with your WiFi password

#define SECRET_CH_ID 1076743    // replace 0000000 with your channel number
#define SECRET_WRITE_APIKEY "2ZXRN1A7U6EWUIX9"   // replace XYZ with your channel write API Key
#define SECRET_READ_APIKEY "BOCRGKV103WDJD6Y"

char ssid[] = SECRET_SSID;   // your network SSID (name) 
char pass[] = SECRET_PASS;   // your network password
int keyIndex = 0;            // your network key Index number (needed only for WEP)
WiFiClient  client;

unsigned long myChannelNumber = SECRET_CH_ID;
const char * myWriteAPIKey = SECRET_WRITE_APIKEY;
const char * myReadAPIKey = SECRET_READ_APIKEY;

// Data Capture
int medicineTaken; // 0 = false, 1 = true
int medicineTakenHour;
int medicineTakenMin; 

// Timing
unsigned long previousMillis;

//Time Library
const char* ntpServer = "pool.ntp.org";
const long  gmtOffset_sec = -18000; // Five hours behind in EST? have to check.
const int   daylightOffset_sec = 3600;


// 24 Hour Passed Token
int Pass24Hour;

// time to eat 
int ReadyToTake; // ready to take the medicine token

void setup() {  
  Serial.begin(115200);  //Initialize serial
  WiFi.mode(WIFI_STA);   
  ThingSpeak.begin(client);  // Initialize ThingSpeak
  previousMillis = millis();
 configTime(gmtOffset_sec, daylightOffset_sec, ntpServer); // setting up time

}

void loop() {
  // Connect or reconnect to WiFi
  if(WiFi.status() != WL_CONNECTED){
    Serial.print("Attempting to connect to SSID: ");
    Serial.println(SECRET_SSID);
    while(WiFi.status() != WL_CONNECTED){
      WiFi.begin(ssid, pass); // Connect to WPA/WPA2 network. Change this line if using open or WEP network
      Serial.print(".");
      delay(5000);     
    } 
    Serial.println("\nConnected.");
  }

  if (millis() - previousMillis < 15000) {
//    Serial.println(medicineTimeTaken);
  } else {
    //medicineAddTime();
    //medicineTimeTaken = ThingSpeak.readRaw(myChannelNumber, String(String("/fields/") + String(1) + String("/created_at")), myReadAPIKey);
//    medicineTimeTaken = ThingSpeak.readCreatedAt(myChannelNumber, myReadAPIKey); // can read the latest time an entry is entered, but for the whole channel, not a specific field..
    //printLocalTime();
    readFutureTime(); 
    previousMillis = millis();
  }

 
}


void readFutureTime() {
  struct tm timeinfo;
  if(!getLocalTime(&timeinfo)) {
    Serial.println("Failed to obtain time");
    return;
  }
  char nowHourChar[30];
  char nowMinChar[30];
  strftime(nowHourChar, 30, "%H", &timeinfo);
  strftime(nowMinChar, 30, "%M", &timeinfo);
  String medicineFutureTime = ThingSpeak.readStringField(myChannelNumber, 1, myReadAPIKey);
  int futureHour = medicineFutureTime.substring(1,3).toInt();
  int futureMin = medicineFutureTime.substring(3).toInt();
  Pass24Hour = ThingSpeak.readIntField(myChannelNumber, 6, myReadAPIKey);
  int nowHour = atoi(nowHourChar);
  int nowMin = atoi(nowMinChar);
//  Serial.println(medicineFutureTime);
//  Serial.println(futureHour);
//  Serial.println(futureMin);
//  Serial.println(nowHour);
//  Serial.println(nowMin);

  if (Pass24Hour == 1) { // Reset this token 00:00 if it has been enabled
    if (nowHour == 0 && nowMin >= 0) { // Its 00:00! --> Update token
      Pass24Hour = 0; // now its time to update 24 hour token
    } else {
      ReadyToTake = 0; // Not time to take it
    }
  } else { // no weird 24Hour edge case
    if (nowHour >= futureHour && nowMin >= futureMin) {
      ReadyToTake = 1; // The hour and the Minute has passed, it is now time to take
    } else {
      ReadyToTake = 0; // Still waiting
    }
    Pass24Hour = 0; // 24 Hour Pass Edge case is 0 still, just explicitly stating here
  }

  int a = ThingSpeak.setField(2, ReadyToTake); // Updating if the time has passed / not and ready to take medicine
  int b = ThingSpeak.setField(6, Pass24Hour); // Updating the Pass24Hour variable
  int c = ThingSpeak.writeFields(myChannelNumber, myWriteAPIKey);
  if(a == 200 & b == 200 & c == 200){
    Serial.println("Channel update successful.");
  } else{
    Serial.println("Problem updating channel. HTTP error code " + String(c));
  } 
}

void medicineAddTime() {
  String nextHour; // Calculting the next time (hour) to take medicine
  String nextMin; // Calculating the next time (minute) to take medicine
  String zeroPlaceholder = String(0); //IDK jank way to add 0 to numeric strings
  String zeroZeroPlaceholder = String("00"); //IDK jank way to add 00 to numeric strings
  String onePlaceholder = String(1); // Using 1 as the first number of the output because otherwise it wont save correctly in ThingSpeak (will remove the 00 entries)
  medicineTakenHour = ThingSpeak.readIntField(myChannelNumber, 4, myReadAPIKey); // When the medicine was consumed Hr
  medicineTakenMin = ThingSpeak.readIntField(myChannelNumber, 5, myReadAPIKey);  // When the medicine was consumed Min
  
//  Serial.println(medicineTakenHour);
//  Serial.println(medicineTakenMin);

  
  medicineTakenHour = (medicineTakenHour  + 1); // Adding 1 hour, using modulus for 24 hour (day)
  if (medicineTakenHour > 24) {
    Pass24Hour = 1; // Set the token saying 24 hours has passed, just to compare the times
    medicineTakenHour = medicineTakenHour % 24; // Making sure to account for 24 hour cycle 
  } else {
    Pass24Hour = 0; // Just set the token as 0, and dont % 24
  }
  
  if (medicineTakenHour < 10) { //In order to format the output when the value is less than 10, with a length 2, 09 vs 9
    if (medicineTakenHour == 0) { 
      nextHour = String("00");  // when 0, output 00
    } else {
      nextHour = String(zeroPlaceholder + medicineTakenHour); // adding a 0 to the single digit value
    }
  } else {
    nextHour = String(medicineTakenHour);
  }

  if (medicineTakenMin < 10) { // do the same for the minutes
    if (medicineTakenMin == 0) {
      nextMin = zeroZeroPlaceholder;
    } else {
      nextMin = String(zeroPlaceholder + medicineTakenMin);
    }
  } else {
    nextMin = String(medicineTakenMin);
  }
  
  String nextTime = String(onePlaceholder + nextHour + nextMin); // Adding a onePlaceholder so that if the time is 00:00, it would not --> 0
  Serial.println("Next Hour: " + nextHour);
  Serial.println("Next Min: " + nextMin);
  Serial.println("Next Time: " + nextTime);
  int a = ThingSpeak.setField(1, nextTime);
  int b = ThingSpeak.setField(6, Pass24Hour);
  int c = ThingSpeak.writeFields(myChannelNumber, myWriteAPIKey);
  if(a == 200 & b == 200 & c == 200){
    Serial.println("Channel update successful.");
  } else{
    Serial.println("Problem updating channel. HTTP error code " + String(c));
  }
}
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
